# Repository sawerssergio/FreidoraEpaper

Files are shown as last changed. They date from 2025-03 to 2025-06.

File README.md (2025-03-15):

# Documentación del Código: Funcionamiento de E-paper, Lectura de Temperatura, MQTT y ArduinoOTA

Este código está diseñado para un dispositivo IoT que utiliza un ESP32 para leer la temperatura de un sensor MAX31865, mostrar información en una pantalla E-paper, conectarse a una red WiFi, comunicarse mediante MQTT y permitir actualizaciones OTA (Over-The-Air). A continuación, se detalla el funcionamiento del código.

---

## **Tabla de Contenidos**
1. [Descripción General](#1-descripción-general)
2. [Configuración Principal](#2-configuración-principal)
3. [Variables y Configuraciones](#3-variables-y-configuraciones)
4. [Funciones de Pantalla](#4-funciones-de-pantalla)
5. [Conectividad WiFi y MQTT](#5-conectividad-wifi-y-mqtt)
6. [Configuración OTA](#6-configuración-ota)
7. [Manejo de MQTT y Entradas](#7-manejo-de-mqtt-y-entradas)
8. [Setup y Loop](#8-setup-y-loop)
9. [Consideraciones Adicionales](#9-consideraciones-adicionales)

---

## **1. Descripción General**
El código está diseñado para un dispositivo IoT que realiza las siguientes funciones:
- **Lectura de temperatura**: Utiliza un sensor MAX31865 para medir la temperatura.
- **Pantalla E-paper**: Muestra información en una pantalla E-paper, incluyendo la temperatura, estado de WiFi, estado de MQTT y mensajes personalizados.
- **Comunicación MQTT**: Se conecta a un servidor MQTT para enviar y recibir datos.
- **Actualización OTA**: Permite actualizar el firmware del dispositivo de forma remota.
- **Control de relés**: Controla hasta 4 relés mediante comandos MQTT.
- **Entradas digitales**: Lee el estado de 3 pulsadores y publica su estado en MQTT.

---

## **2. Configuración Principal**
### **Pines y Configuración Inicial**
- **Pulsadores**: Se utilizan 3 pulsadores conectados a los pines GPIO 36, 39 y 34.
- **Relés**: Se controlan 4 relés conectados a los pines GPIO 33, 25, 26 y 27.
- **Sensor MAX31865**: Configurado en modo 3 hilos, con pines CS (5), CLK (18), MOSI (23) y MISO (19).

### **Configuración WiFi/MQTT**
- **SSID y contraseña**: Se define la red WiFi a la que se conectará el dispositivo.
- **Servidor MQTT**: Dirección IP del servidor MQTT y credenciales de acceso.
- **Dirección IP estática**: Se configura una IP estática para el dispositivo.

### **Configuración E-Paper**
- **Pines E-Paper**: Se definen los pines para la comunicación SPI con la pantalla E-paper.
- **Pantalla**: Se utiliza una pantalla GxEPD2 de 7.5 pulgadas.

---

## **3. Variables y Configuraciones**
### **Variables Globales**
- **Textos de las áreas**: Se almacenan los textos que se muestran en las diferentes áreas de la pantalla E-paper.
- **Temporizadores**: Se utilizan para controlar la frecuencia de actualización de la temperatura, la pantalla y la verificación de conexiones.

### **Librerías Utilizadas**
- **WiFi**: Para la conexión a la red WiFi.
- **PubSubClient**: Para la comunicación MQTT.
- **Adafruit_MAX31865**: Para la lectura del sensor de temperatura.
- **GxEPD2_BW**: Para controlar la pantalla E-paper.
- **Preferences**: Para almacenar datos persistentes en la memoria no volátil del ESP32.
- **ArduinoOTA**: Para permitir actualizaciones OTA.

---

## **4. Funciones de Pantalla**
### **`drawCenteredText`**
- **Descripción**: Dibuja un texto centrado en un área específica de la pantalla.
- **Parámetros**:
  - `text`: Texto a mostrar.
  - `font`: Fuente a utilizar.
  - `x_area`, `y_area`, `w_area`, `h_area`: Coordenadas y dimensiones del área.

### **`updateArea`**
- **Descripción**: Actualiza una área específica de la pantalla con un texto.
- **Parámetros**:
  - `text`: Texto a mostrar.
  - `font`: Fuente a utilizar.
  - `x_area`, `y_area`, `w_area`, `h_area`: Coordenadas y dimensiones del área.

### **`actualizarArea`**
- **Descripción**: Actualiza el contenido de una de las 5 áreas de la pantalla.
- **Parámetros**:
  - `texto`: Texto a mostrar.
  - `area`: Número del área a actualizar (1-5).

### **`dibujarPantallaCompleta`**
- **Descripción**: Redibuja toda la pantalla con los textos actuales de las áreas.

---

## **5. Conectividad WiFi y MQTT**
### **`conectarWiFi`**
- **Descripción**: Conecta el dispositivo a la red WiFi configurada.
- **Comportamiento**: Intenta conectarse hasta 20 veces. Si no lo logra, muestra un mensaje de error.

### **`conectarMQTT`**
- **Descripción**: Conecta el dispositivo al servidor MQTT.
- **Comportamiento**: Si la conexión es exitosa, se suscribe a los topics `relay/#`, `display/#`, `reset` y `refresh`.

---

## **6. Configuración OTA**
### **`configurarOTA`**
- **Descripción**: Configura el servicio OTA para permitir actualizaciones remotas.
- **Comportamiento**: Define un nombre de host y una contraseña para el servicio OTA. Maneja eventos como inicio, progreso, finalización y errores de la actualización.

---

## **7. Manejo de MQTT y Entradas**
### **`callback`**
- **Descripción**: Función que se ejecuta cuando llega un mensaje MQTT.
- **Comportamiento**:
  - Controla los relés si el mensaje llega al topic `relay/#`.
  - Actualiza las áreas de la pantalla si el mensaje llega al topic `display/#`.
  - Reinicia el dispositivo si el mensaje llega al topic `reset`.
  - Redibuja la pantalla si el mensaje llega al topic `refresh`.

### **`verificarEntradas`**
- **Descripción**: Lee el estado de los pulsadores y publica su estado en MQTT.
- **Comportamiento**: Publica "ON" o "OFF" en los topics `valvula`, `tempHot` y `tapa` según el estado de los pulsadores.

---

## **8. Setup y Loop**
### **`setup`**
- **Descripción**: Inicializa el dispositivo.
- **Comportamiento**:
  - Inicia la comunicación serial.
  - Configura los pines de los relés y pulsadores.
  - Inicializa la pantalla E-paper.
  - Conecta a WiFi y MQTT.
  - Configura el servicio OTA.

### **`loop`**
- **Descripción**: Bucle principal del programa.
- **Comportamiento**:
  - Verifica la conexión WiFi y MQTT.
  - Actualiza la temperatura y la publica en MQTT.
  - Verifica el estado de los pulsadores.
  - Maneja las actualizaciones OTA.

---

## **9. Consideraciones Adicionales**
- **Memoria no volátil**: Se utiliza la librería `Preferences` para almacenar el texto del área 1 de la pantalla, de modo que persista después de un reinicio.
- **Eficiencia energética**: La pantalla E-paper entra en modo de hibernación cuando no está en uso para ahorrar energía.

# Resumen de Comandos MQTT

A continuación, se presenta un resumen de los comandos MQTT utilizados en el código, junto con su funcionalidad y cómo interactúan con el dispositivo IoT.

---

## **1. Comandos para Control de Relés**
### **Topic: `relay/#`**
- **Descripción**: Controla el estado de los relés conectados al dispositivo.
- **Formato**: `relay/<número_relé>`
- **Valores**:
  - `ON`: Activa el relé.
  - `OFF`: Desactiva el relé.
- **Ejemplos**:
  - `relay/0 ON`: Activa el relé 0.
  - `relay/1 OFF`: Desactiva el relé 1.

---

## **2. Comandos para Actualizar la Pantalla E-Paper**
### **Topic: `display/#`**
- **Descripción**: Actualiza el contenido de una de las 5 áreas de la pantalla E-paper.
- **Formato**: `display/<número_área>`
- **Valores**: Cualquier texto que se desee mostrar en el área correspondiente.
- **Áreas**:
  - `1`: Área grande (fuente grande, para numero de freidora).
  - `2`: Área de mensajes (fuente mediana).
  - `3`: Área de estado de IP (fuente pequeña).
  - `4`: Área de estado de MQTT (fuente pequeña).
  - `5`: Área de estado de WiFi (fuente pequeña).
- **Ejemplos**:
  - `display/1 25.5°C`: Muestra "10" en el área 1 es ideal que solo sea nuemrico.
  - `display/2 MENSAJE OK`: Muestra "MENSAJE OK" en el área 2.

---

## **3. Comandos para Reiniciar el Dispositivo**
### **Topic: `reset`**
- **Descripción**: Reinicia el dispositivo ESP32.
- **Valores**:
  - `ON`: Reinicia el dispositivo.
- **Ejemplo**:
  - `reset ON`: Reinicia el dispositivo.

---

## **4. Comandos para Refrescar la Pantalla**
### **Topic: `refresh`**
- **Descripción**: Redibuja toda la pantalla E-paper con los textos actuales.
- **Valores**:
  - `ON`: Redibuja la pantalla.
- **Ejemplo**:
  - `refresh ON`: Redibuja la pantalla.

---

## **5. Comandos para Publicar el Estado de los Pulsadores**
### **Topics: `valvula`, `tempHot`, `tapa`**
- **Descripción**: Publica el estado de los pulsadores conectados al dispositivo.
- **Valores**:
  - `ON`: El pulsador está presionado.
  - `OFF`: El pulsador no está presionado.
- **Ejemplos**:
  - `valvula ON`: Indica que el pulsador de la válvula está presionado.
  - `tempHot OFF`: Indica que el pulsador de temperatura caliente no está presionado.

---

## **6. Comandos para Publicar la Temperatura**
### **Topic: `temperatura`**
- **Descripción**: Publica la temperatura medida por el sensor MAX31865.
- **Valores**: Valor numérico de la temperatura en grados Celsius.
- **Ejemplo**:
  - `temperatura 25.5`: Publica una temperatura de 25.5°C.

---

## **Resumen de Topics MQTT**
| **Topic** | **Descripción** | **Valores** | **Ejemplo** |
|---|---|---|---|
| `relay/#` | Control de relés | `ON`, `OFF` | `relay/0 ON` |
| `display/#` | Actualización de áreas de la pantalla | Texto | `display/1 5` |
| `reset` | Reinicia el dispositivo | `ON` | `reset ON` |
| `refresh` | Redibuja la pantalla E-paper | `ON` | `refresh ON` |
| `valvula` | Estado del pulsador de la válvula | `ON`, `OFF` | `valvula ON` |
| `tempHot` | Estado del pulsador de temperatura | `ON`, `OFF` | `tempHot OFF` |
| `tapa` | Estado del pulsador de la tapa | `ON`, `OFF` | `tapa ON`  "Disable" |
| `temperatura` | Publica la temperatura medida | Valor numérico | `temperatura 25.5` |

---

Este resumen proporciona una visión clara de cómo interactuar con el dispositivo IoT mediante MQTT. Cada comando tiene un propósito específico y permite controlar y monitorear el dispositivo de manera remota.
- **Seguridad OTA**: Se recomienda cambiar la contraseña OTA por una más segura antes de implementar el dispositivo en producción.

---

Este código es adecuado para aplicaciones industriales o domésticas donde se requiera monitoreo y control remoto, como en sistemas de climatización, control de procesos o automatización del hogar.

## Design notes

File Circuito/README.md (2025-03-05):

# Documentación del Circuito: Control de Freidoras a Gas con e-Paper IoT

Este documento describe el diseño y funcionamiento de un circuito para controlar freidoras a gas utilizando una pantalla E-paper y comunicación IoT (Internet de las Cosas). El sistema permite monitorear y controlar la temperatura, así como gestionar relés para el encendido y apagado de las freidoras.

---

## **Tabla de Contenidos**
1. [Descripción General](#1-descripción-general)
2. [Lista de Componentes](#2-lista-de-componentes)
3. [Esquemático del Circuito](#3-esquemático-del-circuito)
4. [Explicación de Conexiones](#4-explicación-de-conexiones)
5. [Funcionamiento del Circuito](#5-funcionamiento-del-circuito)
6. [Consideraciones Adicionales](#6-consideraciones-adicionales)

---

## **1. Descripción General**
Este circuito está diseñado para controlar freidoras a gas utilizando una pantalla E-paper y comunicación IoT. El sistema permite:
- Monitorear la temperatura en tiempo real mediante un sensor PT100/PT1000.
- Controlar el encendido y apagado de las freidoras mediante relés.
- Mostrar información en una pantalla E-paper, incluyendo la temperatura y el estado del sistema.
- Permitir actualizaciones de firmware de forma remota (OTA).

---

## **2. Lista de Componentes**
A continuación, se detallan los componentes principales utilizados en el circuito:

| **Componente** | **Cantidad** | **Especificaciones** |
|---|---|---|
| ESP32-WROOM-32 | 1 | Microcontrolador WiFi/Bluetooth |
| MAX31865ATP+ | 1 | Sensor de temperatura PT100/PT1000 |
| Pantalla E-paper | 1 | GxEPD2 7.5 pulgadas, 800x480 píxeles |
| Relés (APAN3112) | 4 | Relé de 5V, 10A |
| Pulsadores (TS-1101-C-W) | 2 | Pulsadores normalmente abiertos (NO) |
| Diodos (1N4148WS-2) | 4 | Diodos de protección para relés |
| Transistores (S8050-MS) | 4 | Transistores NPN para control de relés |
| Regulador de voltaje (LM2596)| 1 | Convertidor DC-DC 24V a 5V |
| Fusible (5x20 BLX-A) | 1 | Fusible de 5x20 mm |
| Capacitores (100nF, 10uF, etc)| Varios | Para filtrado y estabilización |
| Resistencias (10kΩ, 1kΩ, etc)| Varios | Para pull-down, divisores de voltaje, etc|

---

## **3. Esquemático del Circuito**
El esquemático del circuito muestra las conexiones entre los componentes principales. A continuación, se describen las conexiones clave:

### **Conexiones Principales**



- **ESP32**:
  - GPIO 34, 35, 32, 33 → Control de relés.
  - GPIO 14, 12, 13, 15 → Comunicación SPI con la pantalla E-paper.
  - GPIO 18, 19, 23 → Comunicación SPI con el sensor MAX31865.
  - GPIO 0 → Botón de reinicio (BOOT).
  - GPIO 2 → LED indicador.
- **Sensor MAX31865**:
  - Conectado al ESP32 mediante SPI (pines CS, CLK, MOSI, MISO).
  - Configurado en modo 3 hilos para medir la temperatura.
- **Pantalla E-paper**:
  - Conectada al ESP32 mediante SPI (pines CLK, MISO, MOSI, CS, DC, RST, BUSY).
  - Muestra información en tiempo real, como la temperatura y el estado del sistema.
- **Relés**:
  - Controlados por transistores S8050-MS.
  - Cada relé tiene un diodo de protección (1N4148WS-2) para evitar picos de voltaje.
- **Fuente de Alimentación**:
  - Convertidor DC-DC LM2596 para convertir 24V a 5V.
  - Fusible de protección en la entrada de 24V.

---

## **4. Explicación de Conexiones**
### **Pulsadores**
- Cada pulsador está conectado a un pin GPIO del ESP32 y a tierra (GND) a través de una resistencia pull-down de 10kΩ.
- Esto permite leer el estado del pulsador (HIGH o LOW) cuando se presiona o suelta.

### **Relés**
- Los relés están conectados a los pines GPIO del ESP32 para ser controlados digitalmente.
- Cada relé tiene un diodo de protección en paralelo para evitar picos de voltaje.

### **Sensor MAX31865**
- Conectado al ESP32 mediante SPI (pines CS, CLK, MOSI, MISO).
- Utiliza una configuración de 3 hilos para medir la temperatura.

### **Pantalla E-paper**
- Conectada al ESP32 mediante SPI (pines CLK, MISO, MOSI, CS, DC, RST, BUSY).
- Muestra información en tiempo real, como la temperatura y el estado del sistema.

---

## **5. Funcionamiento del Circuito**
El circuito funciona de la siguiente manera:
1. **Inicialización**:
   - El ESP32 se inicia y conecta a la red WiFi.
   - La pantalla E-paper muestra un mensaje de bienvenida.
2. **Lectura de Temperatura**:
   - El sensor MAX31865 mide la temperatura y envía los datos al ESP32.
   - La temperatura se muestra en la pantalla E-paper.
3. **Control de Relés**:
   - El ESP32 recibe comandos MQTT para activar o desactivar los relés.
   - Los relés controlan dispositivos externos, como luces o motores.
4. **Actualización OTA**:
   - El ESP32 permite actualizaciones de firmware de forma remota mediante OTA.
5. **Manejo de Pulsadores**:
   - El estado de los pulsadores se publica en MQTT para su monitoreo remoto.
  
  freidora 1

---

## **6. Consideraciones Adicionales**
### **Precauciones**
- Asegúrate de que la fuente de alimentación sea adecuada para los relés y el ESP32.
- Usa diodos de protección en los relés para evitar daños por picos de voltaje.

### **Mejoras**
- Agregar un sistema de respaldo de batería para evitar cortes de energía.
- Implementar un sistema de registro de datos para almacenar la temperatura en una base de datos.

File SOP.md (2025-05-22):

# Guía de Instalación Paso a Paso para el Código E-paper con MQTT y OTA

## Requisitos Previos PCB FREIDORAS V1.1 
1. **Hardware necesario**: (omitir)
   - Placa ESP32 (recomendado AWK-3131)
   - Pantalla E-paper de 7.5" compatible con GxEPD2
   - Módulo MAX31865 para lectura de temperatura
   - 4 relés
   - 3 pulsadores
   - Fuente de alimentación adecuada

2. **Software necesario**: (Nesesario)
   - Arduino IDE (última versión)
   - ESP32 board package instalado en Arduino IDE
   - Las siguientes librerías (instalables via Library Manager):
     - WiFi
     - PubSubClient
     - Adafruit MAX31865
     - GxEPD2
     - Adafruit GFX Library
     - Preferences
   - Instal driver CP2102para comunicacion serial (https://www.silabs.com/developer-tools/usb-to-uart-bridge-vcp-drivers?tab=downloads)

## Paso 1: Instalación del Entorno de Desarrollo

1. Instala Arduino IDE desde [el sitio oficial](https://www.arduino.cc/en/software)
2. Abre Arduino IDE y ve a `Archivo > Preferencias`
3. En "Gestor de URLs Adicionales de Tarjetas", añade:
   ```
   https://raw.githubusercontent.com/espressif/arduino-esp32/gh-pages/package_esp32_index.json
   ```
4. Ve a `Herramientas > Placa > Gestor de tarjetas` y busca "esp32"
5. Instala "ESP32 by Espressif Systems"

## Paso 2: Instalación de Librerías

1. Ve a `Herramientas > Administrar bibliotecas`
2. Busca e instala las siguientes librerías:
   - "WiFi" (incluida con ESP32)
   - "PubSubClient" by Nick O'Leary
   - "Adafruit MAX31865 library" by Adafruit
   - "GxEPD2" by Jean-Marc Zingg
   - "Adafruit GFX Library" by Adafruit
   - "Preferences" (incluida con ESP32)

## Paso 3: Configuración del Proyecto

1. Crea una nueva carpeta para tu proyecto
2. Dentro de la carpeta, crea un nuevo archivo `.ino` con el código proporcionado
3. Crea una subcarpeta llamada `data` dentro de la carpeta del proyecto
4. En la carpeta `data`, añade el archivo `logo.h` que contiene el bitmap para el logo

## Paso 4: Conexión del Hardware (Omitir)

Conecta los componentes según esta tabla:

| Componente | Pin ESP32 |
|---|---|
| MAX31865 CS | 5 |
| MAX31865 CLK | 18 |
| MAX31865 MOSI | 23 |
| MAX31865 MISO | 19 |
| EPD CLK | 14 |
| EPD MISO | 13 |
| EPD MOSI | 12 |
| EPD CS | 15 |
| EPD DC | 32 |
| EPD RST | 21 |
| EPD BUSY | 22 |
| Pulsador 1 | 36 |
| Pulsador 2 | 39 |
| Pulsador 3 | 34 |
| Relé 1 | 33 |
| Relé 2 | 25 |
| Relé 3 | 26 |
| Relé 4 | 27 |

## Paso 5: Configuración de Red

Modifica estas constantes en el código con tus datos de red:

```cpp
const char* ssid = "vip";
const char* password = "60771800";
const char* mqtt_server = "172.19.32.223";
const char* mqtt_user = "velarde";
const char* mqtt_password = "1234";

IPAddress local_IP(172, 19, 32, 200);
IPAddress gateway(172, 19, 32, 1);
IPAddress subnet(255, 255, 255, 0);
```

## Paso 6: Configuración OTA

Modifica estas líneas si deseas cambiar la configuración OTA:

```cpp
ArduinoOTA.setHostname("FreidoraIoT");
ArduinoOTA.setPassword("12345");
```

## Paso 7: Compilación y Carga del Código

1. Selecciona la placa correcta en `Herramientas > Placa > ESP32 Arduino` (elige tu modelo específico)
2. Configura el Puerto COM correcto
3. Establece la velocidad de upload a 115200
4. Haz clic en el botón "Subir" para compilar y cargar el código

## Paso 8: Configuración del Servidor MQTT

1. Asegúrate de tener un broker MQTT funcionando en `172.19.32.223` (o cambia la IP)
2. Crea los usuarios/configuración necesaria en tu broker MQTT

## Paso 9: Pruebas Iniciales

1. Conecta la alimentación al dispositivo
2. Observa la pantalla E-paper:
   - Debería mostrar el logo inicial
   - La IP asignada
   - El estado de WiFi y MQTT
3. Verifica que puedas conectarte via OTA:
   - Desde Arduino IDE, ve a `Herramientas > Puerto` y busca el dispositivo OTA

## Paso 10: Operación Normal

El dispositivo ahora debería:
- Mostrar la temperatura leída por el MAX31865
- Reaccionar a comandos MQTT en los topics:
  - `relay/#` para controlar relés
  - `display/#` para actualizar áreas de la pantalla
  - `reset` para reiniciar el dispositivo
  - `refresh` para refrescar la pantalla
- Permitir actualizaciones OTA

## Solución de Problemas Comunes

1. **WiFi no se conecta**:
   - Verifica SSID y contraseña
   - Comprueba que la red está disponible
   - Verifica la configuración IP estática

2. **MQTT no se conecta**:
   - Verifica que el broker MQTT está funcionando
   - Comprueba usuario y contraseña
   - Verifica que no hay firewalls bloqueando el puerto 1883

3. **Pantalla no funciona**:
   - Verifica todas las conexiones del E-paper
   - Comprueba que tienes instalada la librería GxEPD2 correcta
   - Asegúrate de que el modelo de pantalla coincide con el definido en el código (GxEPD2_750_T7)

4. **Temperatura no se lee**:
   - Verifica las conexiones del MAX31865
   - Comprueba que el sensor PT100 está bien conectado
   - Verifica la configuración de 3 hilos (3WIRE) en el código

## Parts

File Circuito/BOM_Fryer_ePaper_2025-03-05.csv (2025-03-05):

ID | Name | Designator | Footprint | Quantity | Manufacturer Part | Manufacturer | Supplier | Supplier Part | Price
1 | 10kΩ | R14,R16,R17,R33,R43,R45,R46,R48,R50,R51,R38,R39,R40,R41 | R1206 | 14 | RC1206DR-0710KL | YAGEO(国巨) | LCSC | C326710 | 0.017
2 | 1kΩ | R49,R3,R9,R19,R20,R23,R24,R30,R31 | R0805 | 9 | AS05W2J0102T5E | UNI-ROYAL(厚声) | LCSC | C560481 | 0.029
3 | IRM-90-24_C5656554 | U44 | PWRM-TH_MW_IRM-90-XX | 1 | IRM-90-24 | MW(明纬) | LCSC | C5656554 | 17.988
4 | MAX MX15EDGKM-3.81-08P-GN01-CU-Y-A | U11,U43 | CONN-TH_8P-P3.81_MX15EDGRM-3.81-08P-GN01-CU-A | 2 | MX15EDGRM-3.81-08P-GN01-Cu-A | MAX(迈旭) | LCSC | C5188209 | 0.174
5 | MAX MX15EDGKM-3.81-03P-GN01-CU-Y-A | U46,U47 | CONN-TH_3P-P3.81_MAX_MX15EDGRM-3.81-GN01-03P-CU-A | 2 | MX15EDGRM-3.81-03P-GN01-Cu-A | MAX(迈旭) | LCSC | C5188204 | 0.07
6 | MK-12C02-G020 | SW2 | SW-SMD_MK-12C02-G020 | 1 | MK-12C02-G020 | G-Switch(品赞) | LCSC | C963206 | 0.059
7 | 330uF | C35 | CAP-SMD_BD8.0-L8.3-W8.3-LS9.0-FD | 1 | 25CE330KX | SUNCON(太阳电子) | LCSC | C242040 | 0.388
8 | 330uF | C36 | CAP-SMD_BD8.0-L8.3-W8.3-FD | 1 | EEEFT1V331AP | PANASONIC(松下) | LCSC | C178598 | 0.471
9 | MX15EDGRM-3.81-GN01-03P-CU-A | U37,U42 | CONN-TH_3P-P3.81_MAX_MX15EDGRM-3.81-GN01-03P-CU-A | 2 | MX15EDGRM-3.81-03P-GN01-Cu-A | MAX(迈旭) | LCSC | C5188204 | 0.07
10 | 1N4148WS-2 | D10,D11,D12,D4 | SOD-323_L1.8-W1.3-LS2.5-RD | 4 | 1N4148WS-2 | BORN(伯恩半导体) | LCSC | C306859 | 0.01
11 | APAN3112 | K2,K3,K4,K1 | RELAY-TH_APAN31XX | 4 | APAN3112 | PANASONIC(松下) | LCSC | C91508 | 1.129
12 | FC-2012HRK-620D | LED4,LED5,LED6,LED3 | LED0805-R-RD | 4 | NCD0805R1 | 国星光电 | LCSC | C84256 | 0.012
13 | 2kΩ | R2,R18,R22,R29 | R0805 | 4 | AS05W2J0202T5E | UNI-ROYAL(厚声) | LCSC | C966132 | 0.02
14 | 10kΩ | R21,R25,R32,R47 | R0805 | 4 | CRCW080510K0FKEAHP | VISHAY(威世) | LCSC | C313823 | 0.038
15 | PC817X3YIPW | U8,U16,U18,U10,U26,U27,U28,U32 | OPTO-SMD-4_L6.5-W4.6-P2.54-LS10.0-TL | 8 | PC817X3YIPW | SHARP(夏普) | LCSC | C2833077 | 0.068
16 | S8050-MS | U15,U17,U19,U5 | SOT-23-3_L2.9-W1.3-P1.90-LS2.4-BR | 4 | S8050-MS | MSKSEMI(美森科) | LCSC | C5120746 | 0.015
17 | 1uF | C1,C2,C3,C4,C5,C6,C7 | C0603 | 7 | CL10A105KB8NNNC | SAMSUNG(三星) | LCSC | C15849 | 0.004
18 | 10uF | C23,C26 | C0603 | 2 | CL10A106MQ8NNNC | SAMSUNG(三星) | LCSC | C1691 | 0.004
19 | 100nF | C8,C10 | C0805 | 2 | C0805B104K500NT | TORCH(火炬) | LCSC | C476766 | 0.003
20 | 4.7uF | C9 | C0805 | 1 | CC0805KKX5R9BB475 | YAGEO(国巨) | LCSC | C2897302 | 0.04
21 | 1uF | C11,C12 | C0805 | 2 | CC0805MKX5R8BB105 | YAGEO(国巨) | LCSC | C577038 | 0.015
22 | 22uF | C16,C31,C33 | C0805 | 3 | CL21A226MAYNNNE | SAMSUNG(三星) | LCSC | C602037 | 0.021
23 | 100nF | C25,C27,C30 | C0805 | 3 | CT41G-0805-2X1-50V-0.1μF-K(N) | TORCH(火炬) | LCSC | C126469 | 0.006
24 | 4.7uF | C13 | C0402 | 1 | CL05A475KP5NRNC | SAMSUNG(三星) | LCSC | C368809 | 0.006
25 | 100nF | C14,C15,C17,C18,C19,C20,C21,C22,C32,C34 | C0402 | 10 | CL05B104KO5NNNC | SAMSUNG(三星) | LCSC | C1525 | 0.001
26 | 100nF | U9,U39 | C0402 | 2 | CGA2B3X7R1V104KT0Y0F | TDK | LCSC | C343047 | 0.015
27 | 100nF | C28 | CAP-TH_L13.0-W6.0-P10.00-D0.6 | 1 | MPX104K31C3KN15600 | KNSCHA(科尼盛) | LCSC | C489079 | 0.034
28 | 330uF | C29 | CAP-SMD_BD8.0-L8.3-W8.3-LS9.3-FD-2 | 1 | RVT1C331M0810 330UF 16V | DMBJ(振宝佳) | LCSC | C970700 | 0.052
29 | LESD5D5.0CT1G | D1,D2,D3 | SOD-523_L1.2-W0.8-LS1.6-BI | 3 | LESD5D5.0CT1G | LRC(乐山无线电) | LCSC | C383211 | 0.02
30 | 3 | D5 | SOD-323_L1.7-W1.3-LS2.6-FD-1 | 1 | 1N4148WS | YONGYUTAI(永裕泰) | LCSC | C2892572 | 0.007
31 | 2 | D6 | SOD-323_L1.7-W1.3-LS2.6-FD-1 | 1 | 1N4148WS | YONGYUTAI(永裕泰) | LCSC | C2892572 | 0.007
32 | 1 | D7 | SOD-323_L1.7-W1.3-LS2.6-FD-1 | 1 | 1N4148WS | YONGYUTAI(永裕泰) | LCSC | C2892572 | 0.007
33 | SS34 | D8 | SMA(DO-214AC) | 1 | SS34 | Yenji | LCSC | C142458
34 | ESD9B3.3ST5G-N | D9 | DFN1006-2L-BI | 1 | ESD9B3.3ST5G-N | BORN(伯恩半导体) | LCSC | C316039 | 0.022
35 | S3M | D13 | SMB_L4.6-W3.6-LS5.3-RD | 1 | S3MB | MDD | LCSC | C47524 | 0.031
36 | 5x20 BLX-Atype Fuse holder XC-7 | F1 | FUSE-TH_L22.6-W9.0 | 1 | 5x20 BLX-A型 保险丝支架 XC-7 | xcfuse(旭程) | LCSC | C3131 | 0.067
37 | FPC-05FB-24PH20 | FPC1 | FPC-SMD_24P-P0.50_FPC-05FB-24PH20 | 1 | FPC-05FB-24PH20 | XUNPU(讯普) | LCSC | C2856831 | 0.159
38 | 47uH | L1 | IND-SMD_L12.0-W12.0_CDRH127NP | 1 | CDRH127NP-470MC | Sumida | LCSC | C167265 | 0.69
39 | 68uH | L2 | IND-SMD_L3.5-W3.0 | 1 | SM3521-680MT | SXN | LCSC | C72424 | 0.042
40 | 47mH | L3 | FILTER-TH_B82791H2251N020 | 1 | B82791H2251N020 | TDK | LCSC | C125598 | 1.266
41 | BLM18SP101SH1D | L5 | L0603 | 1 | BLM18SP101SH1D | muRata(村田) | LCSC | C1512135 | 0.092
42 | 0805G (Green) | LED1,LED7,LED8,LED9,LED10,LED11,LED12 | LED0805-R-RD | 7 | KT-0805G | KENTO | LCSC | C2297 | 0.011
43 | SS8050_C2848182 | Q1,Q2 | SOT-23-3_L2.9-W1.6-P1.90-LS2.8-BR | 2 | SS8050 | IDCHIP(英锐芯) | LCSC | C2848182 | 0.012
44 | SI1308EDL | Q4 | SOT-323_L2.0-W1.3-P1.30-LS2.1-BR | 1 | SI1308EDL-VB | VBsemi(微碧半导体) | LCSC | C4355112 | 0.057
45 | 10kΩ | R1 | R0603 | 1 | FRC0603J103TS | FOJAN(富捷) | LCSC | C2930027 | 0.001
46 | 1kΩ | R5 | R0402 | 1 | 0402WGF1001TCE | UNI-ROYAL(厚声) | LCSC | C11702 | 0.001
47 | 10kΩ | R6,R11,R13,R34,R35,R36,R37 | R0402 | 7 | 0402WGF1002TCE | UNI-ROYAL(厚声) | LCSC | C25744 | 0.001
48 | 0Ω | R7,R8 | R0402 | 2 | 0402WGF0000TCE | UNI-ROYAL(厚声) | LCSC | C17168 | 0.001
49 | 22.1kΩ | R10 | R0402 | 1 | 0402WGF2212TCE | UNI-ROYAL(厚声) | LCSC | C43473 | 0.001
50 | 47.5kΩ | R12 | R0402 | 1 | 0402WGF4752TCE | UNI-ROYAL(厚声) | LCSC | C25896 | 0.001
51 | 22Ω | R15 | R0402 | 1 | 0402WGF220JTCE | UNI-ROYAL(厚声) | LCSC | C25092 | 0.001
52 | 10kΩ | R26,R27,R28 | R1206 | 3 | RT1206BRD0710KL | YAGEO(国巨) | LCSC | C136889 | 0.051
53 | 2.55Ω | R4 | R0805 | 1 | RM10FTN2R55 | 大毅科技 | LCSC | C254734 | 0.004
54 | 0Ω | R42 | R0805 | 1 | 0805W8J0000T5E | UNI-ROYAL(厚声) | LCSC | C25275 | 0.002
55 | 100Ω | R44 | R0805 | 1 | FRC0805J101 TS | FOJAN(富捷) | LCSC | C2907294 | 0.001
56 | 470mΩ | U4 | R0805 | 1 | FRL0805FR470TS | FOJAN(富捷) | LCSC | C2930220 | 0.005
57 | 430Ω | U12 | R0805 | 1 | FRC0805F4300TS | FOJAN(富捷) | LCSC | C2907265 | 0.002
58 | 10D561K_C317797 | RV1 | RES-TH_L12.5-W6.2-P7.50-D0.9-S6.20 | 1 | 10D561K | COV(德欣) | LCSC | C317797 | 0.065
59 | TS-1101-C-W | SW4,SW5 | SW-SMD_L6.0-W3.3-LS8.0 | 2 | TS-1101-C-W | XKB Connectivity(中国星坤) | LCSC | C318938 | 0.041
60 | MBR0530_C5204746 | U1,U2,U3 | SOD-123_L2.7-W1.6-LS3.7-RD-1 | 3 | MBR0530 | TWGMC(台湾迪嘉) | LCSC | C5204746 | 0.019
61 | ESP32-WROOM-32(16MB) | U6 | WIFIM-SMD_39P-L25.5-W18.0-P1.27 | 1 | ESP32-WROOM-32-N16 | ESPRESSIF(乐鑫) | LCSC | C529581 | 5.408
62 | CP2102N-A02-GQFN28R | U7 | QFN-28_L5.0-W5.0-P0.50-TL-EP3.3 | 1 | CP2102N-A02-GQFN28R | SKYWORKS/SILICON LABS(芯科) | LCSC | C964632 | 1.927
63 | B2412S-2WR3_C2992384 | U13 | PWRM-TH_YLPTEC_BXXXXS-2WR3 | 1 | B2412S-2WR3 | YLPTEC(易川) | LCSC | C2992384 | 1.989
64 | MX15EDGRM-3.81-08P-GN01-CU-A | U14,U33 | CONN-TH_8P-P3.81_MX15EDGRM-3.81-08P-GN01-CU-A | 2 | MX15EDGRM-3.81-08P-GN01-Cu-A | MAX(迈旭) | LCSC | C5188209 | 0.174
65 | AMS1117-3.3V_C20611856 | U21 | SOT-223-3_L6.5-W3.4-P2.30-LS7.0-BR | 1 | AMS1117-3.3V | TECH PUBLIC(台舟) | LCSC | C20611856 | 0.041
66 | HSMA-C170 | U22,U23,U25,U34,U35 | LED0805-RD | 5 | HSMA-C170 | Broadcom/AVAGO(安华高) | LCSC | C7466711 | 0.212
67 | DBT50-8.25-2P | U24 | CONN-TH_2-P8.25_DBT50-8.25-2P | 1 | DBT50-8.25-2P-BK-P | DORABO(地博电气) | LCSC | C395952 | 0.198
68 | MIC5225-3.3YM5-TR | U29 | SOT-23-5_L3.0-W1.7-P0.95-LS2.8-BL | 1 | MIC5225-3.3YM5-TR | MICROCHIP(美国微芯) | LCSC | C512101 | 0.973
69 | MAX31865ATP+ | U30 | QFN-20_L5.0-W5.0-P0.65-BL-EP | 1 | MAX31865ATP+ | ADI(亚德诺)/MAXIM(美信) | LCSC | C404011 | 3.47
70 | LM2596S-5.0 | U31 | TO-263-5_L10.6-W9.6-P1.70-LS15.9-BR | 1 | LM2596S-5.0/NOPB | Texas Instruments | LCSC | C116713 | 1.719
71 | MICROXNJ | USB1 | MICRO-USB-SMD_MICROXNJ | 1 | MicroXNJ | SHOU HAN(首韩) | LCSC | C404969 | 0.038
72 | MSS12C02LS-BB2.0 | U41 | SW-SMD_MSS12C02LS-HB2.0-1 | 1 | MSS12C02LS-BB2.0 | SHOU HAN(首韩) | LCSC | C3008585 | 0.095

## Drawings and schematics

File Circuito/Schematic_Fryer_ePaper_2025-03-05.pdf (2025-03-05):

# E-PAPER

# Relay 1

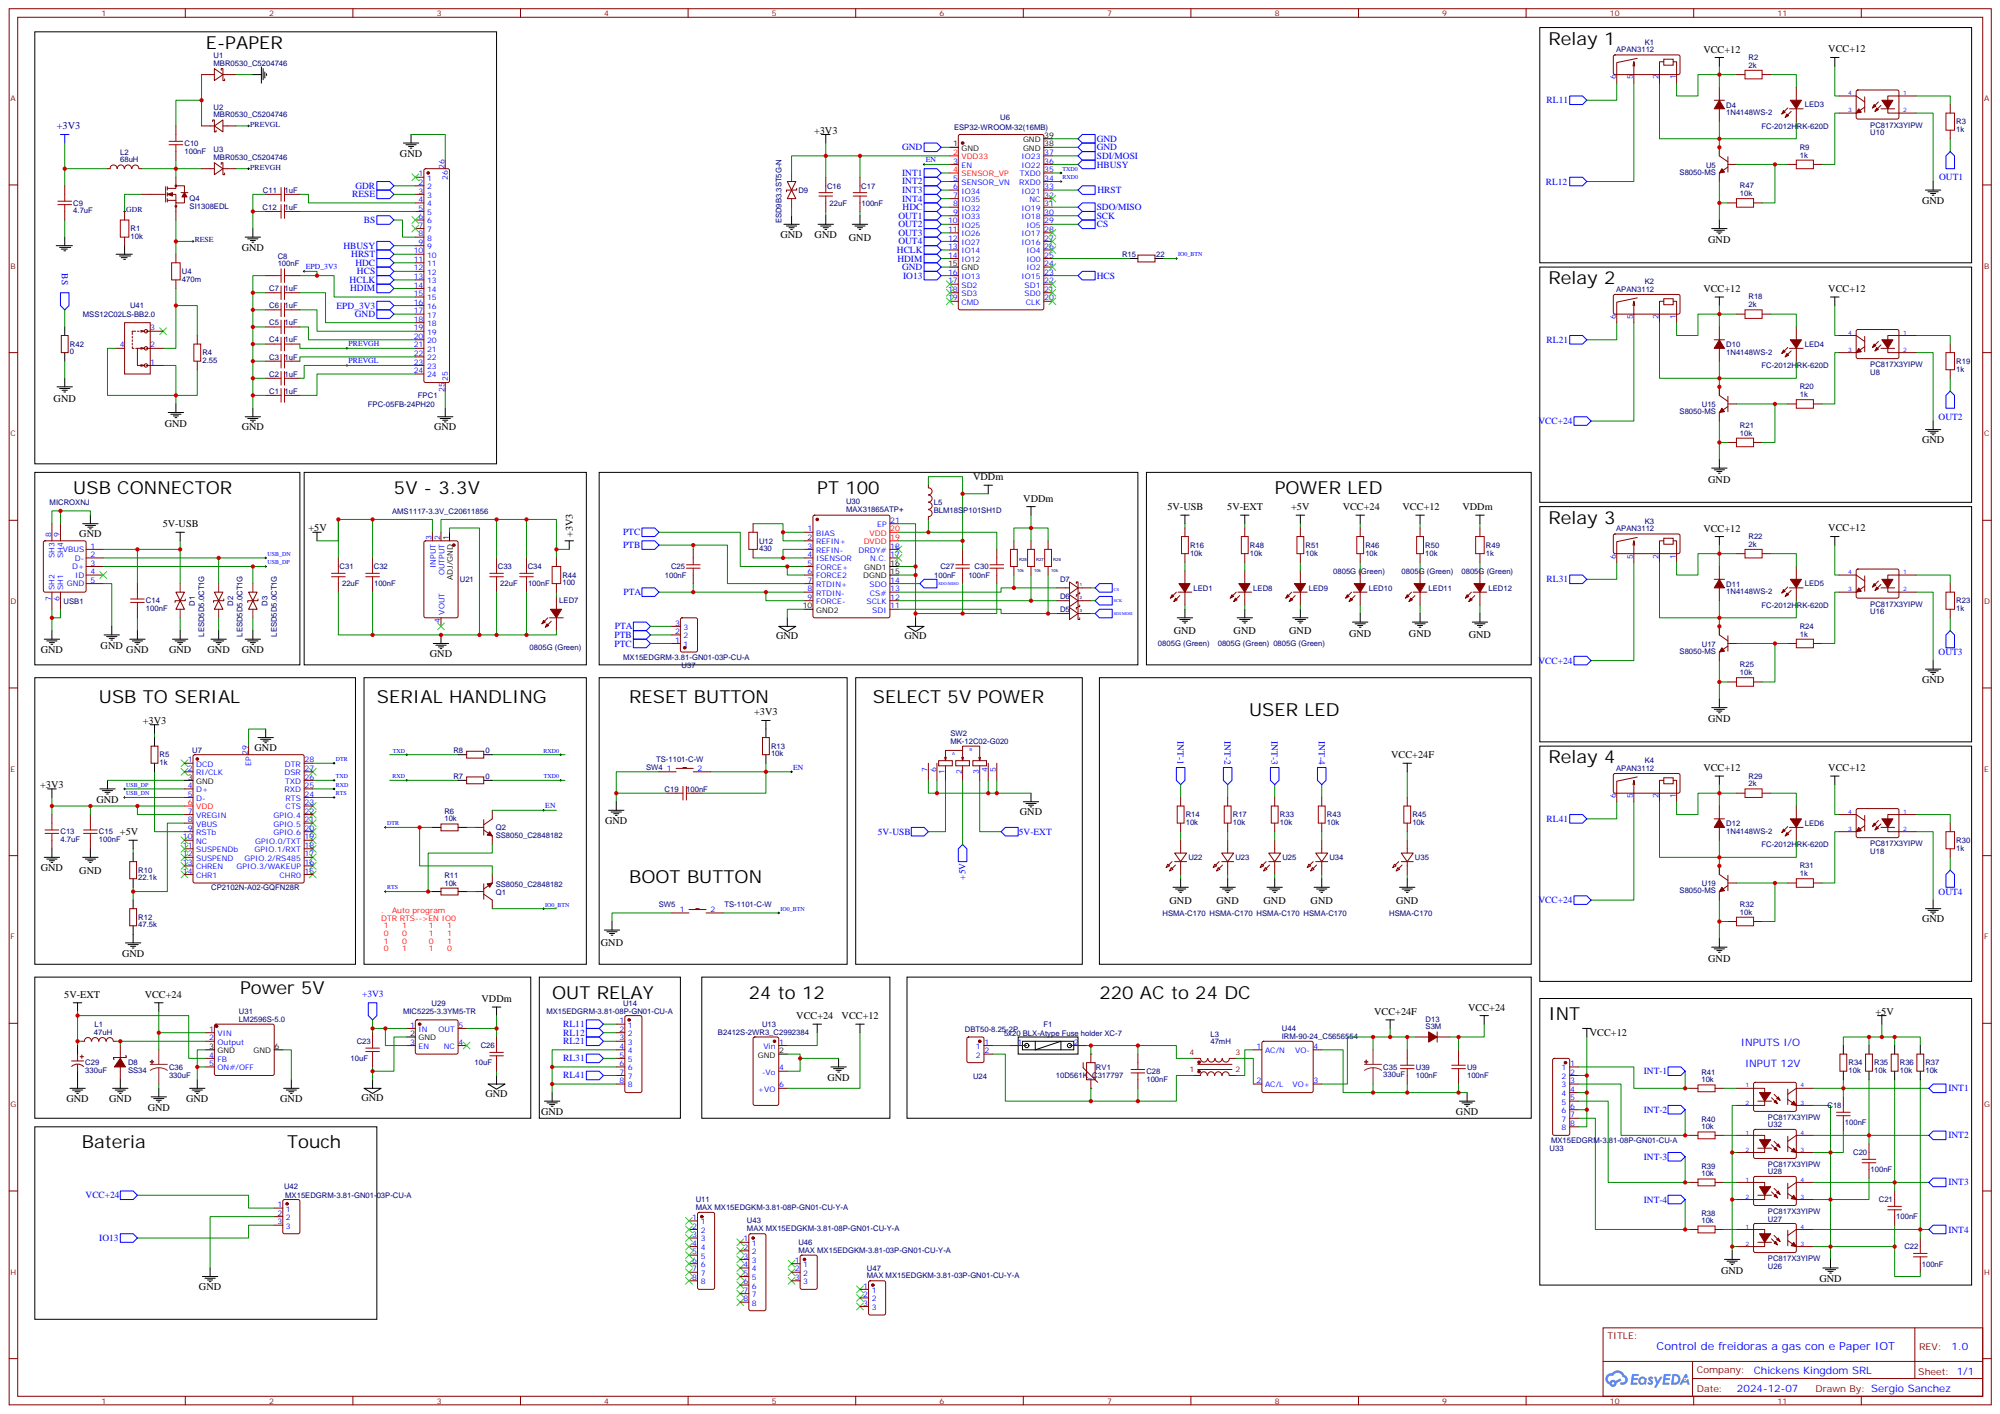
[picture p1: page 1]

5x20 BLX-Atype Fuse holder XC-7

Company: Chickens Kingdom SRL

Drawn By: Sergio Sanchez

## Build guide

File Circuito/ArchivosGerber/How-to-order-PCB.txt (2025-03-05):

How to Order PCB

Please refer to:
https://docs.easyeda.com/en/PCB/Order-PCB

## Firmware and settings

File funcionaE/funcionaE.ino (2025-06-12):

// =================================================================
//      Funcion E-paper Lectura temperatura, MQTT, arduinoOTA
//          Se recomienda usar AWK-3131 Series Industrial 
//             IEEE 802.11n wireless AP/bridge/client
// =================================================================

#include <WiFi.h>
#include <PubSubClient.h>
#include <Adafruit_MAX31865.h>
#include <GxEPD2_BW.h>
#include <Fonts/FreeMonoBold12pt7b.h>
#include <Fonts/FreeMonoBold16pt7b.h>
#include <Fonts/FreeMonoBold24pt7b.h>
#include <Fonts/FreeMonoBold60pt7b.h>
#include <logo.h>
#include <Preferences.h>
#include <ArduinoOTA.h> 

// =================================================================
//                 CONFIGURACIÓN PRINCIPAL
// =================================================================

const int pulsadorGPIO1 = 36;
const int pulsadorGPIO2 = 39;
const int pulsadorGPIO3 = 34;

#define NUM_RELAYS 4
const int relayPins[NUM_RELAYS] = {33, 25, 26, 27};

// Configuración MAX31865
#define RTD_CS   5
#define RTD_CLK  18
#define RTD_MOSI 23
#define RTD_MISO 19

Adafruit_MAX31865 thermo(RTD_CS, RTD_MOSI, RTD_MISO, RTD_CLK);

// =================================================================
//                 VARIABLES EN FUNCION LA RED
// =================================================================

// Configuración WiFi/MQTT
const char* ssid = "iPhone de Sergio";
const char* password = "sawers88";
const char* mqtt_server = "200.58.77.84";
const char* mqtt_user = "villa";
const char* mqtt_password = "sawers";

IPAddress local_IP(172, 20, 10, 5);
IPAddress gateway(172, 20, 10, 1);
IPAddress subnet(255, 255, 255, 0);
IPAddress primaryDNS(172, 20, 10, 1);
IPAddress secondaryDNS(8, 8, 4, 4);


// Configuración E-Paper
#define EPD_CLK   14
#define EPD_MISO  13
#define EPD_MOSI  12
#define EPD_CS    15
#define EPD_DC    32
#define EPD_RST   21
#define EPD_BUSY  22

GxEPD2_BW<GxEPD2_750_T7, GxEPD2_750_T7::HEIGHT> display(GxEPD2_750_T7(EPD_CS, EPD_DC, EPD_RST, EPD_BUSY));

// =================================================================
//                 VARIABLES GLOBALES
// =================================================================
WiFiClient espClient;
PubSubClient client(espClient);
Preferences preferences;

String area1Text = "-";
String area2Text = "MENSAJE OK";
String area3Text = "IP: ---.---.---.---";
String area4Text = "MQTT: OFF";
String area5Text = "WIFI: OFF";

unsigned long lastTempUpdate = 0;
unsigned long lastDisplayUpdate = 0;
unsigned long lastReconnectAttempt = 0;
unsigned long lastFcCheck = 0;
unsigned long lastWifiCheck = 0;
wl_status_t lastWifiStatus = WL_IDLE_STATUS;

// =================================================================
//                 FUNCIONES DE PANTALLA
// =================================================================
void drawCenteredText(const char* text, const GFXfont* font, uint16_t x_area, uint16_t y_area, uint16_t w_area, uint16_t h_area) {
  int16_t tx, ty;
  uint16_t tw, th;
  display.setFont(font);
  display.setTextColor(GxEPD_BLACK);
  display.getTextBounds(text, 0, 0, &tx, &ty, &tw, &th);

  uint16_t x = x_area + (w_area - tw)/2 - tx;
  uint16_t y = y_area + (h_area/2) + (th/2) - ty;
  y -= 20;

  display.setCursor(x, y);
  display.print(text);
}

void updateArea(const char* text, const GFXfont* font, uint16_t x_area, uint16_t y_area, uint16_t w_area, uint16_t h_area) {
  display.setPartialWindow(x_area, y_area, w_area, h_area);
  display.firstPage();
  do {
    //display.fillScreen(GxEPD_WHITE);
    drawCenteredText(text, font, x_area, y_area, w_area, h_area);
    display.fillRect(0, 288, 800, 12, GxEPD_BLACK);
    display.fillRect(200, 300, 12, 180, GxEPD_BLACK);
    display.fillRect(588, 300, 12, 180, GxEPD_BLACK);
  } while (display.nextPage());
}

void actualizarArea(const String& texto, int area) {
  switch(area) {
    case 1:
      area1Text = texto;
      updateArea(area1Text.c_str(), &FreeMonoBold60pt7b, 0, 210, 180, 250);
      preferences.begin("epaper", false);
      preferences.putString("area1", area1Text);
      preferences.end();
      break;
    case 2:
      area2Text = texto;
      updateArea(area2Text.c_str(), &FreeMonoBold16pt7b, 212, 300, 376, 90);
      break;
    case 3:
      area3Text = texto;
      updateArea(area3Text.c_str(), &FreeMonoBold12pt7b, 212, 390, 376, 90);
      break;
    case 4:
      area4Text = texto;
      updateArea(area4Text.c_str(), &FreeMonoBold12pt7b, 600, 300, 200, 90);
      break;
    case 5:
      area5Text = texto;
      updateArea(area5Text.c_str(), &FreeMonoBold12pt7b, 600, 390, 200, 90);
      break;
  }
}

void dibujarPantallaCompleta() {
  display.setFullWindow();
  display.firstPage();
  do {
    display.fillScreen(GxEPD_WHITE);
    display.drawBitmap(233, 16, kingdomlogoking, 334, 256, GxEPD_BLACK);
    display.fillRect(0, 288, 800, 12, GxEPD_BLACK);
    display.fillRect(200, 300, 12, 180, GxEPD_BLACK);
    display.fillRect(588, 300, 12, 180, GxEPD_BLACK);

    drawCenteredText(area1Text.c_str(), &FreeMonoBold60pt7b, 0, 210, 180, 250);
    drawCenteredText(area2Text.c_str(), &FreeMonoBold16pt7b, 212, 300, 376, 90);
    drawCenteredText(area3Text.c_str(), &FreeMonoBold12pt7b, 212, 390, 376, 90);
    drawCenteredText(area4Text.c_str(), &FreeMonoBold12pt7b, 600, 300, 200, 90);
    drawCenteredText(area5Text.c_str(), &FreeMonoBold12pt7b, 600, 390, 200, 90);
  } while (display.nextPage());
  //display.hibernate();
}

// =================================================================
//                 CONECTIVIDAD
// =================================================================
void conectarWiFi() {
  if (!WiFi.config(local_IP, gateway, subnet, primaryDNS, secondaryDNS)) {
    actualizarArea("ERROR IP", 3);
  }

  WiFi.begin(ssid, password);
  actualizarArea("CONECTANDO...", 3);

  int intentos = 0;
  while (WiFi.status() != WL_CONNECTED && intentos++ < 20) {
    delay(500);
    display.hibernate();
    display.init(0);
  }

  if (WiFi.isConnected()) {
    actualizarArea("IP: " + WiFi.localIP().toString(), 3);
  } else {
    actualizarArea("ERROR WIFI", 3);
  }
}

void conectarMQTT() {
  if (client.connect("FreidoraIoT", mqtt_user, mqtt_password)) {
    client.subscribe("relay/#");      // Suscríbete al topic "relay"
    client.subscribe("display/#");    // Suscríbete al topic "display/1 etc.."
    client.subscribe("reset");        // Suscríbete al topic "reset"
    client.subscribe("refresh");      // Suscríbete al topic "refresh"
    actualizarArea("MQTT: OK", 4);
  } else {
    actualizarArea("MQTT: ERROR", 4);
  }
}

// =================================================================
//                 CONFIGURACIÓN OTA
// =================================================================
void configurarOTA() {
  ArduinoOTA.setHostname("FreidoraIoT");  // Nombre del dispositivo OTA
  // Configurar contraseña OTA
  ArduinoOTA.setPassword("12345"); // <-- Añade tu contraseña aquí

  ArduinoOTA.onStart([]() {
    String type;
    if (ArduinoOTA.getCommand() == U_FLASH) {
      type = "sketch";
    } else {  // U_SPIFFS
      type = "filesystem";
    }
    Serial.println("Iniciando actualización OTA: " + type);
    actualizarArea("OTA UPDATE", 2);
  });

  ArduinoOTA.onEnd([]() {
    Serial.println("\nActualización completada");
    actualizarArea("OTA COMPLETE", 2);
  });

  ArduinoOTA.onProgress([](unsigned int progress, unsigned int total) {
    Serial.printf("Progreso: %u%%\r", (progress / (total / 100)));
    actualizarArea("OTA: " + String(progress / (total / 100)) + "%", 2);
  });

  ArduinoOTA.onError([](ota_error_t error) {
    Serial.printf("Error[%u]: ", error);
    if (error == OTA_AUTH_ERROR) {
      Serial.println("Error de autenticación");
      actualizarArea("OTA ERROR: AUTH", 2);
    } else if (error == OTA_BEGIN_ERROR) {
      Serial.println("Error al iniciar");
      actualizarArea("OTA ERROR: BEGIN", 2);
    } else if (error == OTA_CONNECT_ERROR) {
      Serial.println("Error de conexión");
      actualizarArea("OTA ERROR: CONNECT", 2);
    } else if (error == OTA_RECEIVE_ERROR) {
      Serial.println("Error de recepción");
      actualizarArea("OTA ERROR: RECEIVE", 2);
    } else if (error == OTA_END_ERROR) {
      Serial.println("Error al finalizar");
      actualizarArea("OTA ERROR: END", 2);
    }
  });

  ArduinoOTA.begin();
  actualizarArea("OTA LISTO", 2);
}


// =================================================================
//                        MQTT Y ENTRADAS 
// =================================================================
void callback(char* topic, byte* payload, unsigned int length) {
  char mensaje[50];
  length = length < 49 ? length : 49;
  memcpy(mensaje, payload, length);
  mensaje[length] = '\0';

  if (strncmp(topic, "relay/", 6) == 0) {
    int relay = atoi(topic + 6);
    if (relay >= 0 && relay < NUM_RELAYS) {
      digitalWrite(relayPins[relay], strcmp(mensaje, "ON") == 0 ? HIGH : LOW);
    }
  }
  else if (strncmp(topic, "display/", 8) == 0) {
    int area = atoi(topic + 8);
    if (area >= 1 && area <= 5) {
      actualizarArea(String(mensaje), area);
    }
  }else if (strcmp(topic, "reset") == 0) { // Nueva condición para reset
    if (strcmp(mensaje, "ON") == 0) {
      ESP.restart(); // Reinicia el ESP32
    }
  } else if (strcmp(topic, "refresh") == 0) { // Nueva condición para refresh
    if (strcmp(mensaje, "ON") == 0) {
      dibujarPantallaCompleta(); // Redibuja la pantalla completa
    }
  }
}

void verificarEntradas() {
  static bool estadoAnterior[3] = {LOW, LOW, LOW};
  bool estadosActuales[3] = {
    digitalRead(pulsadorGPIO1),
    digitalRead(pulsadorGPIO2),
    digitalRead(pulsadorGPIO3)
  };

  const char* topics[3] = {"valvula", "tempHot", "tapa"};
  for (int i = 0; i < 3; i++) {
    if (estadosActuales[i] != estadoAnterior[i]) {
      client.publish(topics[i], estadosActuales[i] ? "ON" : "OFF");
      estadoAnterior[i] = estadosActuales[i];
    }
  }
}

// =================================================================
//                 SETUP Y LOOP
// =================================================================
void setup() {
  Serial.begin(115200);

  preferences.begin("epaper", true);
  area1Text = preferences.getString("area1", "-");
  preferences.end();

  SPI.begin(EPD_CLK, EPD_MISO, EPD_MOSI, EPD_CS);
  display.init(0);
  display.setRotation(0);
  dibujarPantallaCompleta();

  for (int i = 0; i < NUM_RELAYS; i++) {
    pinMode(relayPins[i], OUTPUT);
    digitalWrite(relayPins[i], LOW);
  }
  pinMode(pulsadorGPIO1, INPUT_PULLDOWN);
  pinMode(pulsadorGPIO2, INPUT_PULLDOWN);
  pinMode(pulsadorGPIO3, INPUT_PULLDOWN);

  thermo.begin(MAX31865_3WIRE);
  conectarWiFi();
  ArduinoOTA.setHostname("FreidoraIoT");
  ArduinoOTA.begin();
  client.setServer(mqtt_server, 1883);
  client.setCallback(callback);
  conectarMQTT();
}

void loop() {
  unsigned long ahora = millis();

  // Control WiFi
  if (ahora - lastWifiCheck > 5000) {
    wl_status_t currentStatus = WiFi.status();
    if (currentStatus != lastWifiStatus) {
      if (currentStatus == WL_CONNECTED) {
        actualizarArea("WIFI: OK", 5);
      } else {
        actualizarArea("WIFI: OFF", 5);
      }
      lastWifiStatus = currentStatus;
    }
    lastWifiCheck = ahora;
  }

  // Control MQTT
  if (!client.connected() && (ahora - lastReconnectAttempt > 5000)) {
    actualizarArea("RECONEC...", 4);
    conectarMQTT();
    lastReconnectAttempt = ahora;
  }
  client.loop();

  // Actualizar temperatura
  if (ahora - lastTempUpdate > 2000) {
    float temp = thermo.temperature(100.0, 430.0);
    if (!thermo.readFault()) {
      client.publish("temperatura", String(temp).c_str());
    }
    lastTempUpdate = ahora;
  }

  // Verificar entradas
  if (ahora - lastFcCheck > 100) {
    verificarEntradas();
    lastFcCheck = ahora;
  }
  // Manejo de OTA
  ArduinoOTA.handle();
}

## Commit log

2025-03-05 subiendo documentacion
    [BOM_Fryer_ePaper_2025-03-05.csv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]
2025-03-05 circuito readme
2025-03-05 Update README.md
    readme de los circuitos
